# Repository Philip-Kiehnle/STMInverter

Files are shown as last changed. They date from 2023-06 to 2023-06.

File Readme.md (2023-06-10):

# STMInverter - PV inverter based on STM32F030

This project was inspired by some disused PV modules. Instead of recycling the modules, they were upcycled.
Mounted on a wood storage shed, they can produce some energy and protect the wood from rainwater at the same time👍  
The picture shows the installation with two of four modules mounted.
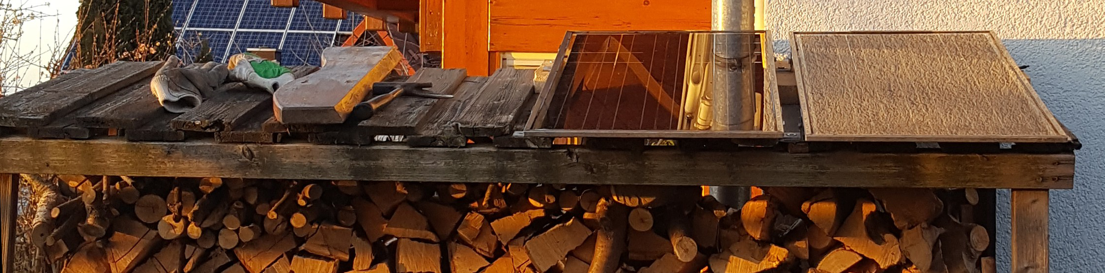
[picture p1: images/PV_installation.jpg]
PV_installation PV installation 50% complete


But in order to use the solar power in a comfortable way, an inverter is necessary. Let's build a small PV inverter!

System overview:
```
  __________________________________     _________________     _____________     __________     __________________
 |                                  |   |                 |   |             |   |          |   |                  |
 | 2 strings parallel               |   |  Capacitor bank |   |             |   |          |   | 16.43 V to 230 V |
 |   2 x 53 W PV modules per string |-->|   6 x 1.1 mF    |-->| Full-bridge |-->| L-filter |-->| 50Hz transformer |
 |   17.6 Vmpp per module           |   |                 |   |             |   |          |   |                  |
 |__________________________________|   |_________________|   |_____________|   |__________|   |__________________|
```
## Controller

The inverter is controlled by a microcontroller, which runs the following elements:
```
  _____________      ____________________        _____________________        ___       _____________
 |             | V  |                    |  I   |                     |  V   |   | V   |             |
 | MPP-Tracker |--->| Voltage controller | ---> | Current feedforward | ---> | + |---> | dutycycle   |--> PWM
 |  (ToDo)     |    |                    |      |   (sensorless)      |      | + |     | calculation |
 |_____________|    |____________________|      |_____________________|      |___|     |_____________|
                                                 __________                    ^
                                       V_grid   |          |   V_grid_estim    |
                                       -------> | SOGI-PLL | ------------------
                                                |__________|
```

##### MPP-Tracker = Maximum Power Point Tracker
extracts maximum power from PV modules

##### Voltage controller
controls the DC-voltage to the desired voltage of the MPP-Tracker

In single phase systems, a 100Hz DC-link power ripple occurs.  
In order to  keep this ripple away from the controller, we calculate:

$$\begin{aligned} V_\mathrm{c} &= V_\mathrm{c0} + \frac{1}{C} \cdot \int_0^t (i_\mathrm{pv}-i_\mathrm{out}) \mathrm{d}t \\
               &= V_\mathrm{c0} + \frac{1}{C} \cdot ( i_\mathrm{pv} \cdot t - \int_0^t (\frac{V_\mathrm{ac,amp} I_\mathrm{ac,amp} \sin^2(\omega t)}{V_\mathrm{dc}}) \mathrm{d}t ) \\
               &= V_\mathrm{c0} + \frac{1}{C} \cdot ( i_\mathrm{pv} \cdot t - \frac{V_\mathrm{ac,amp} I_\mathrm{ac,amp}}{V_\mathrm{dc}} \cdot (-\underbrace{\frac{\sin(\omega t) \cdot \cos(\omega t)}{2\omega}}_{\frac{\sin(2\omega)}{4\omega}} + \frac{t}{2} ))
\end{aligned}$$

Thus, the ac-part of the capacitor voltage is:

$$V_\mathrm{c,ac} = \frac{V_\mathrm{ac,amp} I_\mathrm{ac,amp}}{C \cdot V_\mathrm{dc} \cdot 4\omega} \cdot \sin(2\omega t) $$

##### Current feedforward (sensorless)
calculates the output voltage based on the desired current from the voltage controller using the system model. No current sensor is installed. The current control is not steady-state accurate, but this is not a problem, because of the superimposed voltage controller.

##### SOGI-PLL = Second-order Generalized Integrator Phase-Locked Loop
detects the grid voltage and phase for feedforward control

## Simulation
In order to simulate the control alogrithms, see pythonSimulation/Readme.md
[pythonSimulation/Readme.md](pythonSimulation/Readme.md)

## Implementation

The STM32CubeIDE and the integrated STM32CubeMX init code generation tools are used to program the microcontroller.

## Results
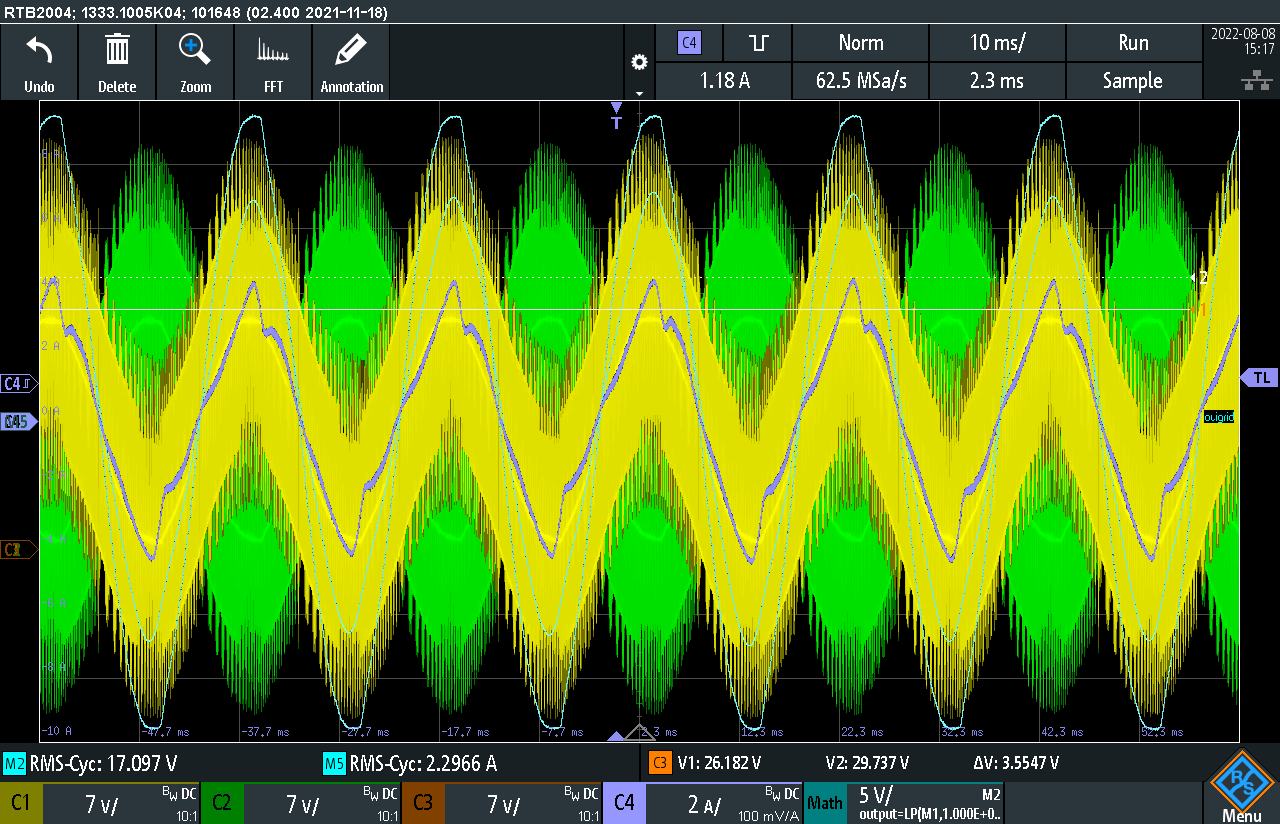
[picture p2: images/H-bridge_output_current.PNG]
Osci output current

All measurements are taken at the low-voltage side of the transformer:  
Chn1(yellow) and Chn2(green) show the full-bridge PWM output voltages.  
Chn3(orange) shows the DC-voltage (no curve visible).  
Chn4(blue) shows the output current.  
Math channels show the low-pass filtered output voltage and current. -> Vout and Iout are in-phase.

# Todo
Implement MPP-Tracker. At the moment, 30V Mosfets are used which limit the voltage, so an MPP-Tracker is useless.

The amplitude of the PLL quadrature signals, v and qv matches the amplitude of the input signal v only when the centre frequency of the filter, ω matches the input frequency.  
-> ω feedback has to be implemented. Otherwise, in case of grid frequency variations the feedforwarded grid voltage has different amplitude.

The PLL detects 50Hz only. If pure sinusoidal current should be fed into the grid, more sophisticated PLL structures or current controllers are necessary. But this approach seems to be a grid-friendly approach, since harmonics are partially compensated by the inverter.

For grid islandig detection, more sophisticated methods should be implemented. At the moment, the grid is valid if 50Hz +-1Hz and Vgrid_amplitude_nom +-10% are detected.  

Design a combined PCB for the controller and the power stage and get rid of the breadboard demonstrator with an old 30V Mosfet power stage protoype.

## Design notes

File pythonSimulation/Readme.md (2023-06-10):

# Python framework for testing C algorithms

Python is used to simulate real world data in order to test inverter control algorithms and the Phase-Locked-Loop(PLL), which are written in C language.

# How to build

1. Compile C-Files to shared objects
``` 
cc -fPIC -shared -o controller.so src/controller.c src/sogi_pllFXP.c
```

2. Run python file
``` 
./inverterSimulation.py
```

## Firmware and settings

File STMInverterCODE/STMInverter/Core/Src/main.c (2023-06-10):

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
/* Includes ------------------------------------------------------------------*/
#include "main.h"

/* USER CODE BEGIN Includes */
#include <stdlib.h>
#include <stdbool.h>
//#include <stdio.h>
#include <string.h>
#include "controller.h"
#include "sogi_pllFXP.h"
/* USER CODE END Includes */

/* USER CODE BEGIN PD */

#define SHUTDOWN_MASK (1<<6)  // Gatedriver Shutdown Pin + LED (inverted)

enum state_t {INIT, POWER_TEST, GRID_CONNECTING, GRID_SYNC};
volatile enum state_t state = INIT;

/* USER CODE END PD */

ADC_HandleTypeDef hadc;
DMA_HandleTypeDef hdma_adc;

TIM_HandleTypeDef htim1;

UART_HandleTypeDef huart1;

/* USER CODE BEGIN PV */
uint16_t ADCxConvertedData[2];
uint16_t adcOff;
volatile uint16_t debug_Vdc_filt;
volatile int16_t debug_i_ref_amp;
volatile int16_t debug_v_amp_pred;

volatile bool status_Vin = false;
volatile bool status_Vgrid = false;

volatile uint32_t cnt_intr;
volatile uint32_t cnt_crowbar_actions;
/* USER CODE END PV */

void SystemClock_Config(void);
static void MX_GPIO_Init(void);
static void MX_DMA_Init(void);
static void MX_ADC_Init(void);
static void MX_TIM1_Init(void);
static void MX_USART1_UART_Init(void);
/* USER CODE BEGIN 0 */
// Redirect standard output to the UART port
//int _write(int file, char *ptr, int len)
//{
//    HAL_UART_Transmit(&huart1,(uint8_t *)ptr,len, 10);
//    return len;
//}

#define uSend(x) uartSend(x, sizeof x -1)
void uartSend(char* ptr, int len)
{
    HAL_UART_Transmit(&huart1,(uint8_t *)ptr,len, 10);

}

//volatile bool conv_done = false;
//void HAL_TIM_TriggerCallback(TIM_HandleTypeDef *htim)

// 30kHz / ((5+1)/2) = 10kHz
#define CTRL_FREQ 10000
// execution time = 77.19us
// PV voltage applied until first execution of this callback:
// 500µs soft ramp of Buck-Conv + 4.2ms when controller has >3V = 4.7ms
// maximum PV current: 6A -> 6mF * 28V /6A = 28.0ms -> enough time for crowbar to limit Vin

//void HAL_TIM_PeriodElapsedCallback(TIM_HandleTypeDef *htim)
void HAL_ADC_ConvCpltCallback(ADC_HandleTypeDef *hadc)
{

  //HAL_GPIO_TogglePin(GPIOA, GPIO_PIN_5);
  GPIOA->BSRR = (1<<5); //set PA5
  //conv_done = true;
  cnt_intr++;

  // Lowpass filter for Vdc
  static uint16_t Vdc_prev[3] = {0};
  uint16_t Vdc_filt = ((uint32_t)ADCxConvertedData[0] + Vdc_prev[0] + Vdc_prev[1] + Vdc_prev[2]) >> 2;
  debug_Vdc_filt = Vdc_filt;
  Vdc_prev[2] = Vdc_prev[1];
  Vdc_prev[1] = Vdc_prev[0];
  Vdc_prev[0] = ADCxConvertedData[0];


  // #######################
  // ### error checking  ###
  // #######################

  // Vin
  if (Vdc_filt > VIN_MIN_RAW && Vdc_filt < VIN_MAX_RAW) {
	  if (Vdc_filt > VIN_START_RAW) {
		  status_Vin = true;
	  }
  } else {
	  GPIOA->BSRR = SHUTDOWN_MASK;  // disable PWM & yellow LED
	  GPIOF->BRR = 1<<1;  // disable contactor
	  status_Vin = false;
	  state = INIT;
  }

  // Vin crowbar to limit input PV voltage
  if (Vdc_filt > VIN_CROWBAR_MAX_RAW) {
	  GPIOA->BSRR = 1<<4;  // enable PV crowbar
	  cnt_crowbar_actions++;
  } else if (Vdc_filt < VIN_CROWBAR_MIN_RAW) {
	  GPIOA->BRR = 1<<4;  // disable PV crowbar
  }

  // Vgrid
  int32_t vd = pll_get_vd();
  int32_t w = pll_get_w();
  static uint32_t cnt_pll_locked = 0;
  if (vd > VD_MIN_RAW && vd < VD_MAX_RAW &&
	   w > W_MIN_RAW && w < W_MAX_RAW) {
	  if (cnt_pll_locked == 0.2*CTRL_FREQ) {  // 200ms
		  status_Vgrid = true;
	  } else {
		  cnt_pll_locked++;
	  }
  } else {
	  status_Vgrid = false;
	  cnt_pll_locked = 0;
  }

  // #################
  // ### read ADC  ###
  // #################

  // Now configured in auto trigger mode

  // DMA mode takes 6.02us for 3 channels; 5.92uS without if(HAL_OK) -> 20us-6us = 14us -> 14us*48MHz = 672 cycles
  //static uint16_t   aADCxConvertedData[ADC_CONVERTED_DATA_BUFFER_SIZE];

  /* ### - 4 - Start conversion in DMA mode ################################# */
  //HAL_ADC_Start_DMA(&hadc, (uint32_t *)aADCxConvertedData, ADC_CONVERTED_DATA_BUFFER_SIZE );


  // polling mode takes 6.25us (for 1channel?)
//	    /*##-3- Start the conversion process #######################################*/
//	    if (HAL_ADC_Start(&hadc) != HAL_OK)
//	    {
//	      /* Start Conversation Error */
//	      Error_Handler();
//	    }
//
//	    /*##-4- Wait for the end of conversion #####################################*/
//	    /*  For simplicity reasons, this example is just waiting till the end of the
//	    conversion, but application may perform other tasks while conversion
//	    operation is ongoing. */
//	    if (HAL_ADC_PollForConversion(&hadc, 10) != HAL_OK)
//	    {
//	      /* End Of Conversion flag not set on time */
//	      Error_Handler();
//	    }
//	    else
//	    {
//	      /* ADC conversion completed */
//	      /*##-5- Get the converted value of regular channel  ########################*/
//	    	aADCxConvertedData[0] = HAL_ADC_GetValue(&hadc);
//	    }

  int16_t duty1 = 0;
  static uint32_t cnt_rel = 0;
  cnt_rel++;

#define PWM_MAX 800
#define PWM_MAX_HALF (PWM_MAX>>1)

	  int16_t phase = pll_singlephase_step(ADCxConvertedData[1]-adcOff);

  switch (state) {
  	  case INIT:
  		  GPIOF->BRR = 1<<1;  // disable contactor
  		  GPIOA->BSRR = SHUTDOWN_MASK;  // disable PWM & yellow LED
//  		  if (status_Vin  && (cnt_rel >= 10*CTRL_FREQ)) {  // wait 10sec, cnt_rel exactly equal (==) seems to causes hangup in morning startup
		  if (status_Vin) {
  			  state = POWER_TEST;
  			  cnt_crowbar_actions = 0;
  			  cnt_rel = 0;
  		  }
  		  break;

  	  case POWER_TEST:

  		  // higher power consumption through sine generation -> safety risk
//  		  static int16_t phase_gridforming = 0;
//  		  phase_gridforming += ((1<<15)*50)/CTRL_FREQ;
//  		  duty1 = PWM_MAX_HALF + ( (int32_t)( (PWM_MAX_HALF*(VGRID_AMP/VGRID_TRATIO)/VDC_REF)*(int32_t)cos1(phase_gridforming) ) >> 15 );
//		  GPIOA->BRR = SHUTDOWN_MASK;  // enable PWM

		  // If crowbar has a lot of work to do in the first 30 seconds -> enough power is available
		  if (cnt_crowbar_actions > 1080) {
			  state = GRID_CONNECTING;
			  cnt_rel = 0;
		  }

		  if (cnt_rel >= 30*CTRL_FREQ) {  // if still here after 30 sec -> reset microcontroller
			  NVIC_SystemReset();  // most efficient way to get back to first state
		  }
  		  break;

  	  case GRID_CONNECTING:
  		 GPIOF->BSRR = 1<<1;  // enable contactor
  		 if (cnt_rel == 0.025*CTRL_FREQ) {  // 25ms delay for contactor action
  			state = GRID_SYNC;
  			cnt_rel = 0;
  			piCtrl.y = 0;
  			piCtrl.x_prev = 0;
  		 }
  		 break;

  	  case GRID_SYNC:

		  // #########################
		  // ### control algorithm ###
		  // #########################

		  if (status_Vgrid) {

#define EXTEND_LOC 5
#define SCALE_VAC2VDC (int32_t)( ((VGRID_ADCR/VGRID_TRATIO) / VIN_ADCR ) * (1<<EXTEND_LOC) )

			cnt_rel = 0;
			//int16_t i_ref_amp = step_pi_Vdc2IacAmp( VDC_REF_RAW, Vdc_filt );
			int16_t i_ref_amp = step_pi_Vdc2IacAmp_volt_comp( VDC_REF_RAW, Vdc_filt, phase );
			debug_i_ref_amp = i_ref_amp;

			int16_t duty_pll = ( pll_get_vd()*SCALE_VAC2VDC * PWM_MAX_HALF / Vdc_filt ) >> EXTEND_LOC;

			//int16_t v_amp_pred = 20*step_IacAmp2VacSecAmp(i_ref_amp);  // 10 Ohm resistor test + 130uH  22.4ns rise time 24.18V/22.0Vdc
			//int16_t v_amp_pred = 40*step_IacAmp2VacSecAmp(i_ref_amp);  // 10 Ohm resistor test + 130uH  36.5ns rise time 22.3V/22.0Vdc bzw. 10.4ns rise time 27.53V/21.78Vdc
								                                         // ohne Gate Ausschaltdioden 26ns rise time 22.19V/21.4Vdc -> minimal overshoot
			int16_t v_amp_pred = calc_IacAmp2VacSecAmpDCscale(i_ref_amp);
			debug_v_amp_pred = v_amp_pred;
			int16_t duty_v_amp_pred = ( v_amp_pred * PWM_MAX_HALF ) / Vdc_filt;

			// irefamp 3,3A -> 13,7W  7,6A ->30W  11,1A -> 43W  12,2V->49W(25,2-27,6Vdc)

			// fixed L and R Trafo + winding parallel
			//int16_t phase_shiftRL = get_IacPhase();  // Strom eilt 505us vor 10,5W 12,5VA
			//int16_t phase_shiftRL = get_IacPhase() + (int16_t)(((1<<15)*-0.505)/20); //IAC_AMP_MAX 12.0  // 38W/45VA Strom(4Aamp) eilt 1,8ms nach (23,6Voutamp 27,4Vdc)
			// bei kleinen Strömen eilt Strom vor, bei großen nach -> keine Kompensation
			//int16_t phase_shiftRL = get_IacPhase(); // Strom eilt 1.08ms nach bei 4,2Aamp
			int16_t phase_shiftRL = get_IacPhase()+ (int16_t)(((1<<15)*1.08)/20);  // Strom(3,5Aamp) in Phase bei 40,5W/42,5VA (25,4Vdc bis 27,3Vdc)

			//duty1 = PWM_MAX_HALF + ( ( PWM_MAX_HALF*(int32_t)cos1(phase) ) >> 15 );  // MAX amplitude test
			//duty1 = PWM_MAX_HALF + ( ( (duty_v_amp_pred)*(int32_t)cos1(phase) ) >> 15 );  //resistor test; asymm, maybe because of Oszi
			duty1 = PWM_MAX_HALF + ( ( (duty_pll*(int32_t)cos1(phase) + duty_v_amp_pred*(int32_t)cos1(phase+phase_shiftRL)) ) >> 15 );

			static uint32_t cnt_power_low = 0;

			if (i_ref_amp < I_REF_AMP_MIN_RAW) {
				cnt_power_low++;
				if (cnt_power_low == 30*CTRL_FREQ ) {  // 30 sec low power -> reset microcontroller
					NVIC_SystemReset();
				}
			} else {
				cnt_power_low = 0;
			}

			GPIOA->BRR = SHUTDOWN_MASK;  // enable PWM & yellow LED

  		  } else {
			  GPIOA->BSRR = SHUTDOWN_MASK;  // disable PWM & yellow LED
			  if (cnt_rel == 30*CTRL_FREQ) {  // 30 sec no valid grid -> reset microcontroller
				  NVIC_SystemReset();
			  }
  		  }

		  break;
	}

	  // single PWM step has 1/48MHz = 20.83ns
#define MIN_PULSE 4  // min pulse duration is 83ns - 50ns deadtime = 33ns
	  if (duty1 > (PWM_MAX-MIN_PULSE)) {
		  duty1 = PWM_MAX;
	  } else if (duty1 < MIN_PULSE){
		  duty1 = 0;
	  }

	  // A leg
	  __HAL_TIM_SetCompare(&htim1, TIM_CHANNEL_3, duty1);  //update pwm value

	  // B leg
	  int16_t duty2 = PWM_MAX_HALF+(PWM_MAX_HALF-duty1);
	  __HAL_TIM_SetCompare(&htim1, TIM_CHANNEL_1, duty2);  //update pwm value
	  __HAL_TIM_SetCompare(&htim1, TIM_CHANNEL_2, duty2);  //update pwm value


	  GPIOA->BRR = (1<<5); //switch off PA5

}



/* USER CODE END 0 */

/**
  * @brief  The application entry point.
  * @retval int
  */
int main(void)
{
  /* MCU Configuration--------------------------------------------------------*/

  /* Reset of all peripherals, Initializes the Flash interface and the Systick. */
  HAL_Init();

  /* Configure the system clock */
  SystemClock_Config();

  /* Initialize all configured peripherals */
  MX_GPIO_Init();
  MX_DMA_Init();
  MX_ADC_Init();
  MX_TIM1_Init();
  MX_USART1_UART_Init();
  /* USER CODE BEGIN 2 */

  GPIOA->BSRR = SHUTDOWN_MASK;  // disable PWM & yellow LED

  char Tx_Buffer[64];
  uint8_t Tx_len;

//  HAL_UART_Transmit(&huart1,(uint8_t *)Tx_Buffer,Tx_len, 10);
  //HAL_UART_Transmit_IT(&huart1,(uint8_t *)Tx_Buffer,Tx_len);


  // ###########################
  // ### Timer configuration ###
  // ###########################

  if (  HAL_TIMEx_PWMN_Start(&htim1, TIM_CHANNEL_1) != HAL_OK)
  {
    /* PWM Generation Error */
    Error_Handler();
  }
  if (   HAL_TIM_PWM_Start(&htim1, TIM_CHANNEL_2) != HAL_OK)
  {
    /* PWM Generation Error */
    Error_Handler();
  }
  if (   HAL_TIM_PWM_Start(&htim1, TIM_CHANNEL_3) != HAL_OK)
  {
    /* PWM Generation Error */
    Error_Handler();
  }
  if (  HAL_TIMEx_PWMN_Start(&htim1, TIM_CHANNEL_3) != HAL_OK)
  {
    /* PWM Generation Error */
    Error_Handler();
  }

  if (  HAL_TIM_Base_Start_IT(&htim1) != HAL_OK)
  {
    Error_Handler();
  }

  if ( HAL_ADC_Start_DMA(&hadc, (uint32_t *)ADCxConvertedData, sizeof(ADCxConvertedData)/sizeof(ADCxConvertedData[0]))  != HAL_OK)
  {
    Error_Handler();
  }

	// get ADC offset -> can be done once for every new microcontroller
//    uint32_t adc_sum = 0;
//	for (int i=0; i < (1<<15); i++ ) {
//	  /* ### - 4 - Start conversion in DMA mode ################################# */
//	  //HAL_ADC_Start_DMA(&hadc, (uint32_t *)ADCxConvertedData, sizeof(ADCxConvertedData)/sizeof(ADCxConvertedData[0]));
//	  while (!conv_done) {
//		  asm("nop");
//	  }
//
//	  conv_done = false;
//	  adc_sum += ADCxConvertedData[1];
//	}
//	adcOff = adc_sum >> 15;
//
//	uSend("\nADCcal ");
//	itoa(adcOff, Tx_Buffer, 10);
//	Tx_len=strlen(Tx_Buffer);
//	HAL_UART_Transmit(&huart1, (uint8_t *)Tx_Buffer, Tx_len, 10);
//	uSend("\n");

	adcOff = 943-9;  //+0 : 200mAdc 3,5W/20VA  +10:390mAdc   -9: 40mAdc 2,7W/13VA  0,5W/10VA/1,3Irefamp
	pll_set_phaseOffset((1<<15) * -10.03/20);  // zero crossing of grid and converter voltage matched

  /* USER CODE END 2 */

  /* Infinite loop */
  /* USER CODE BEGIN WHILE */
  while (1)
  {
    /* USER CODE END WHILE */

    /* USER CODE BEGIN 3 */

	  //HAL_IWDG_Refresh(&hiwdg);

	  //if (cnt_intr % CTRL_FREQ == 0) {  // V1: once a second
	  // V2: on data request
	  uint8_t Rx_Buffer = 0;
	  HAL_UART_Receive(&huart1, &Rx_Buffer, 1, 10);

	  if (Rx_Buffer == 'p') {

		  uSend("state");
		  itoa(state, Tx_Buffer, 10);
		  Tx_len=strlen(Tx_Buffer);
		  HAL_UART_Transmit(&huart1, (uint8_t *)Tx_Buffer, Tx_len, 10);

		  if (status_Vin) {
			  uSend(" Vin:ok");
		  }
		  if (status_Vgrid) {
			  uSend(" Vgrid:ok");
		  }

		  uSend("\ncnt_crowbar_actions");
		  itoa(cnt_crowbar_actions, Tx_Buffer, 10);
		  Tx_len=strlen(Tx_Buffer);
		  HAL_UART_Transmit(&huart1, (uint8_t *)Tx_Buffer, Tx_len, 10);

		  uSend("\nvd");
		  itoa((pll_get_vd()*(uint16_t)VGRID_ADCR) >> ADC_BITS, Tx_Buffer, 10);
		  Tx_len=strlen(Tx_Buffer);
		  HAL_UART_Transmit(&huart1, (uint8_t *)Tx_Buffer, Tx_len, 10);

		  uSend("\nw");
		  itoa(pll_get_w()*100/((1<<15)-1), Tx_Buffer, 10);
		  Tx_len=strlen(Tx_Buffer);
		  HAL_UART_Transmit(&huart1, (uint8_t *)Tx_Buffer, Tx_len, 10);

		  uSend("\nVdc");
		  itoa((debug_Vdc_filt * (uint16_t) (10*VIN_ADCR)) >> ADC_BITS, Tx_Buffer, 10);
		  Tx_len=strlen(Tx_Buffer);
		  HAL_UART_Transmit(&huart1, (uint8_t *)Tx_Buffer, Tx_len, 10);

		  uSend("\nIrefAmp");
		  itoa((debug_i_ref_amp*10*(uint16_t)IGRID_ADCR) >> ADC_BITS, Tx_Buffer, 10);
		  Tx_len=strlen(Tx_Buffer);
		  HAL_UART_Transmit(&huart1, (uint8_t *)Tx_Buffer, Tx_len, 10);

//		  uSend("\nVdcR");
//		  itoa(Vdc_filt, Tx_Buffer, 10);
//		  Tx_len=strlen(Tx_Buffer);
//		  HAL_UART_Transmit(&huart1, (uint8_t *)Tx_Buffer, Tx_len, 10);
//
//		  uSend("\nVacR");
//		  itoa(ADCxConvertedData[1], Tx_Buffer, 10);
//		  Tx_len=strlen(Tx_Buffer);
//		  HAL_UART_Transmit(&huart1, (uint8_t *)Tx_Buffer, Tx_len, 10);
//
//		  uSend("\nIrefAmpR");
//		  itoa(debug_i_ref_amp, Tx_Buffer, 10);
//		  Tx_len=strlen(Tx_Buffer);
//		  HAL_UART_Transmit(&huart1, (uint8_t *)Tx_Buffer, Tx_len, 10);
//
//		  uSend("\nv_amp_predR");
//		  itoa(debug_v_amp_pred, Tx_Buffer, 10);
//		  Tx_len=strlen(Tx_Buffer);
//		  HAL_UART_Transmit(&huart1, (uint8_t *)Tx_Buffer, Tx_len, 10);

		  uSend("\n\n");
	  }
	  //HAL_Delay(1000);  //ms
  }
  /* USER CODE END 3 */
}

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


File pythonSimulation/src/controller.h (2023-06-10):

/*
 * sogi_pllFXP.h
 *
 *  Created on: 23.07.2022
 *      Author: philip
 */

#ifndef INC_CONTROLLER_H_
#define INC_CONTROLLER_H_

#include <stdint.h>

#define ADC_BITS 12
int32_t get_ADC_BITS();

//#define VIN_ADCR (1.04 * 3.3 * 190/10)  // adc range in volts [0,62.7V]  30V real shows as 29.6V -> 1,0135; 25,2÷24,8=1,016
#define VIN_ADCR (1.055 * 3.3 * 190/10)  // adc range in volts ~[0,62.7V]
int32_t get_VIN_ADCR();

#define VIN_MIN 24.5  //25
#define VIN_MIN_RAW ((1<<ADC_BITS)*VIN_MIN/VIN_ADCR)
#define VIN_START 26.0  //32
#define VIN_START_RAW ((1<<ADC_BITS)*VIN_START/VIN_ADCR)
#define VDC_REF 29.0  // todo implement MPP Tracker
#define VDC_REF_RAW ((1<<ADC_BITS)*VDC_REF/VIN_ADCR)
#define VIN_CROWBAR_MIN 30.0
#define VIN_CROWBAR_MIN_RAW ((1<<ADC_BITS)*VIN_CROWBAR_MIN/VIN_ADCR)
#define VIN_CROWBAR_MAX 31.5
#define VIN_CROWBAR_MAX_RAW ((1<<ADC_BITS)*VIN_CROWBAR_MAX/VIN_ADCR)
#define VIN_MAX 35.0
#define VIN_MAX_RAW ((1<<ADC_BITS)*VIN_MAX/VIN_ADCR)

#define VGRID_AMP 325
#define VGRID_TRATIO 14  // transformer winding ratio
int32_t get_VGRID_TRATIO();
#define C (6*1100e-6)
float get_C();

//#define VGRID_ADCR (1.04 * 3.3 * 325/0.67)  // signed; additional transformer winding scales 325V down  // same 50Hz
#define VGRID_ADCR (1.056 * 3.3 * 325/0.67)  // signed; additional transformer winding scales 325V down  // same RMS
int32_t get_VGRID_ADCR();
#define VD_MIN_RAW ((1<<ADC_BITS)* 0.9 * VGRID_AMP/VGRID_ADCR)
#define VD_MAX_RAW ((1<<ADC_BITS)* 1.15 * VGRID_AMP/VGRID_ADCR)


#define SCALE_F2WRAW  ((1<<15) -1)
#define F_MIN 49
#define W_MIN_RAW F_MIN*SCALE_F2WRAW
#define F_MAX 51
#define W_MAX_RAW F_MAX*SCALE_F2WRAW

#define IGRID_ADCR 30  // [-15,+15A]; no grid current sensor is used at the moment
int32_t get_IGRID_ADCR();
#define IAC_AMP_MAX 10  //(6 * sqrt(2))  // ToDo 6,2Aamp sind in echt nur 4,2Aamp, bei 7 hat Automat ausgelöst -> Phase shift, dann okay, aber nur 50Wout -> 8A, okay
// -> 8.5A sind 55Watt_grid -> 55/0,9=61Wdc -> Ziel:5Aac_sec * 16,4V=82Wdc -> 74Wgrid -> Strom um 34% erhöhen auf 11,39
// -> 10 works reliable, without triggering the circuit breaker -> 65Watt_grid
// 18.02.2023: 2.2Arefamp = 8.2W/11.9VA sehr leiser Betrieb
#define IAC_AMP_MAX_RAW ((1<<ADC_BITS) * IAC_AMP_MAX/IGRID_ADCR)
#define I_REF_AMP_MIN 1.4  // todo fix when current scale fixed  1.2refamp -> 0.3W Einspeisung
#define I_REF_AMP_MIN_RAW ((1<<ADC_BITS) * I_REF_AMP_MIN/IGRID_ADCR)


typedef struct {
	int32_t y;
	int32_t y_min;
	int32_t y_max;
	int32_t x_prev;
	int32_t c1;  // (Ki*T/2 + Kp)
	int32_t c2;  // (Ki*T/2 - Kp)
} piController;


extern piController piCtrl;
void pi_step(int32_t x, piController *ctrl);

int16_t calc_IacAmp2VacSecAmpDCscale(int32_t i_amp);
int16_t get_IacPhase();
int32_t step_predict_i(int32_t i_ref, int32_t i);
int16_t step_pi_Vdc2IacAmp(int32_t vdc_ref, int32_t vdc);
int16_t step_pi_Vdc2IacAmp_volt_comp(int32_t vdc_ref, int32_t vdc, int16_t phase);
int16_t step_pi_Vdc2IacAmp_charge_comp(int32_t vdc_ref, int32_t vdc, int32_t vac_sec_VDCscale, int32_t i_ref_VDCscale);

int16_t sin1(int16_t angle);
int16_t cos1(int16_t angle);

#endif /* INC_CONTROLLER_H_ */

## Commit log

2023-06-10 removed current offset; turnoff okay; 50% capacitor voltage ripple feedforward
2023-06-10 reduced number of starts; 100% capacitor voltage ripple feedforward; sometimes switchoff at full power
2023-06-10 Software: - reduced number of starts - improved random switchoff at full power by increasing VIN_MAX - increased grid current -> grid feedin power 65 Watt - 3 month test passed Hardware: - added sche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
    [Half-Bridge.kicad_sch, STMInverter.kicad_sch]

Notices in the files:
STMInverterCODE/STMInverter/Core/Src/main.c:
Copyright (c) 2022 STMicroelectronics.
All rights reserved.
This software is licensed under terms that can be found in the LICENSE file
